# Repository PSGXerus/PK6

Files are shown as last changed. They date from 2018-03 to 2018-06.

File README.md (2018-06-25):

# Raspberry Pi 3 powered kiosk

- [Introduction](#introduction)
  - [Scope](#scope)
  - [Audience](#audience)
  - [Documentation](#documentation)
  - [Acronyms](#acronyms)
- [1. Components](#1-components)
- [2. Milestones (Roadmap)](#2-milestones-roadmap)
- [3. Software](#3-software)
- [4. Hardware](#4-hardware)
- [5. Power consumption](#5-power-consumption)
- [6. Installation](#6-installation)
- [Appendix](#appendix)
  - [Useful webpages](#useful-webpages)

## Introduction

### Scope

This repository shows the work in progress of the TI project summer 2018 no. 6. 

### Audience

This document should be a guide for future participants in the project. 

### Documentation

* [Automatic TOC generation](http://tableofcontent.eu/)
* [General form](https://docs.gitlab.com/ee/user/markdown.html)
* [Table generator](http://www.tablesgenerator.com/markdown_tables)
* Markdown editor 
	- Windows & Linux: [Ghostwriter](https://wereturtle.github.io/ghostwriter/)
	- MacOS: [Macdown](https://macdown.uranusjr.com/)

### Acronyms

**OS** Operating System

## 1. Components

| Unit | Component |
|:---|:---:|
| Compute unit | Raspberry Pi 3 B |
| Screen | [Waveshare 10.1" HDMI LCD(H)](https://www.waveshare.com/wiki/10.1inch_HDMI_LCD_(H))|
| OS | [Raspbian Stretch](https://www.raspberrypi.org/downloads/raspbian/) |

## 2. Milestones (Roadmap)

- [x] Building development system
- [x] Putting touchscreen into operation
- [x] Creating standby logic
    - [x] Concept
    - [x] Design
    - [x] Test
- [x] Hosting a fullscreen application
	- [x] Implement button functionality
		- [x] Build button test setup
		- [x] Create python software drivers
		- [x] Solder buttons
	- [x] Set up GUI
		- [x] Implement GUI
		- [x] Test GUI on the Raspberry 
	- [x] Integration
- [x] Creating a case
	- [x] Concept
	- [x] Design
	- [x] Manufacture
	- [x] Paint
- [x] Integrating admin access
- [x] Writing setup-bashscript

## 3. Software

- Modifications on the OS can be found in [this](documentation/mods.md) document.
- The application development is descibend in [this](documentation/sw.md) document.
- The documentation for the modified bootloader can be found [here](documentation/bootloader.md).

## 4. Hardware

- Everything concerning hardware is described in [this](documentation/hw.md) document.

## 5. Power consumption

|Nominal Voltage|Measured Current|Consumed Power|
|---|---|---|
|12V |~0.5A |~6W |

## 6. Installation

1. Download [Raspbian](https://www.raspberrypi.org/downloads/raspbian/)
2. Put a freshly formatted micro SD card into your laptop
3. Start a terminal
4. Navigate with ```cd [path]``` and ```ls``` to the folder with the downloaded Image
5. Type the following command

    ```shell
    $ sudo fdisk -l
    ```

6. Memorize the name for the SD card handle (probably /dev/mmcblk0)
7. Type this name as the \<PATH\> in this command

    **BE CAREFUL**: If \<PATH\> is not correct ```dd``` could wipe your laptops storage!!!
    
    ```shell
    $ sudo umount <PATH>
    $ sudo dd bs=1M if=./<NAME_OF_THE_IMAGE> of=<PATH>
    ```
7. Mount the SD cards boot partition
8. Add the following to the end of *cmdline.txt* on the boot partition, with \<IP\>, \<GATEWAY\> and \<BROADCAST\> set as desired

    ```
    ip=<IP>::<GATEWAY>:<BROADCAST>:rpi:eth0:off
    ```
9. Add the following to the end of *config.txt* on the boot partition

    ```
    dtoverlay=gpio-poweroff,active_low="y"
    dtoverlay=gpio-shutdown,gpio_pin=20
    ```
10. Unmount the SD card and put it into the Raspberry Pi you want to use in the kiosk
11. Boot and open a terminal
12. Use the following commands

    ```shell
    $ passwd
    # Set a password
    # Check if network is available
    $ ping 8.8.8.8
    $ git clone https://github.com/PSGXerus/PK6_2018.git
    $ cd PK6_2018/install
    $ sudo ./initialize_pi.sh &> ~/install.log
    ```

## Appendix

### Useful webpages
  
[Add a power button to the Raspberry](https://howchoo.com/g/mwnlytk3zmm/how-to-add-a-power-button-to-your-raspberry-pi)
[Original project descripton (DE)](http://www.netzmafia.de/skripten/hardware/RasPi/Projekt-Kiosk/)  
[Pi 3 Kiosk (DE)](https://itrig.de/index.php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)  
[Various Information on the Raspberry Pi (DE)](http://www.elektronik-kompendium.de/sites/raspberry-pi/index.htm)

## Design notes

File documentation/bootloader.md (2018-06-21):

# Modified Plymouth boot splashscreen

Boot splash screens on Raspbian are currently displayed by plymouth.  
Plymouth is an application that runs very early in the boot process
(even before the root filesystem is mounted!) that provides a graphical
boot animation while the boot process happens in the background.
Plymouth themes are usually written in C but Plymouth also ships a script parser
which can be used to create simple boot splash screens.

- [Developing Plymouth splash screens](#developing-plymouth-splash-screens)
- [Installing the splash screen from this repository](#installing-the-splash-screen-from-this-repository)
- [Further reading](#further-reading)

## Developing Plymouth splash screens

An animation for plymouth can be created with the help of the 3D tool [blender](https://www.blender.org/download/).

To develop your own plymouth script install the following packages.

```shell
$ sudo apt install plymouth-themes
$ sudo apt install plymouth-x11
```

A sample script can now be found in */usr/share/plymouth/themes/script*.

```shell
$ sudo plymouth-set-default-theme script
$ cp <src/bootloder/test_plymouth.sh> .
$ ./test_plymouth.sh
```

Refer to [further reading](#further-reading) for more information on the scripting syntax.

## Installing the splash screen from this repository

Execute the following commands.
 
```shell
$ sudo cp -r <src/bootloder/raspberry_pi> /usr/share/plymouth/themes
$ sudo plymouth-set-default-theme raspberry_pi
$ sudo cp -r <src/bootloder/plymouth-quit.service.d> /etc/systemd/system 
$ sudo systemctl daemon-reload
```

## Further reading

- [Plymouth scripting guide](http://brej.org/blog/?p=158)
- [Plymouth scripting Syntax](https://www.freedesktop.org/wiki/Software/Plymouth/Scripts/)
- [Plymouth git repository](https://github.com/sergeysova/plymouth)

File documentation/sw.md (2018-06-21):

# Kiosk System

###### Hochschule München - Projekt Technische Informatik Nr. 6 - SS18

## Einleitung

Der sogenannte Kiosk-Modus eines Betriebssystems zeichnet sich durch eingeschränkte Rechte für den Benutzer aus, um ausschließlich gewünschte Inhalte zu zeigen. 
Möchte man eine Python Applikation für einen Raspberry Pi mit Raspbian programmieren, die Webinhalte oder lokale HTML Dateien in einem Kiosk Modus anzeigt und per Hardware-Taster kontrollierbar macht, ist folgendes Vorgehen möglich.

### Wahl der graphischen Benutzeroberfläche

Python bietet einige GUI Pakete wie *TKinter*, *PySide* oder *PyQT*. Da sich die Umsetzung einer Web-Ansicht mit dem Python Standard *TKinter* allerdings nur schwierig umsetzen lässt, ist *PyQt5* besser geeignet. Zudem ist *Qt* ist ein plattformübergreifender Standard für die Entwicklung von graphischen Benutzeroberflächen und für den Raspberry Pi bestens geeignet. Die Evaluierung anderer Pakete wurde deshalb nicht mehr in Betracht gezogen.

### GPIO Ports verwenden

Der Raspberry Pi besitzt einige General Purpose Input Output (GPIO) Ports, deren Status mithilfe der Python GPIO Methoden ausgelesen werden kann. Die Hardware Komponenten sind daher an diese Ports angeschlossen.

### Taster

Im Kiosk Projekt kommen 3 Taster zum Einsatz. Hiervon ist ein Taster Teil des Drehgebers, der aber genauso angesprochen wird wie die restlichen beiden Taster. Die Taster sind jeweils mit externen 10 kOhm Pull-Up Widerständen verbunden (Invertierte Logik). Details befinden sich in der Code Dokumentation.

### Drehgeber

Bei der Drehung um einen Einrastpunkt emittiert ein typischer Drehgeber auf seinen 2 Ausgangspins einen 2 Bit Gray Code. Jeder Schritt, der meistens durch einen physikalischen Klick begleitet wird, generiert dabei eine Sequenz an 5 Output Codes.

Position  | Bit1 | Bit2
--------- | ---- | ------
Start 		| 0		| 0
1/4  		| 1		| 0
1/2			| 1		| 1
3/4			| 0		| 1
Ende		| 0 	| 0

Die Richtung der Drehbewegung wird durch den Ablauf der Codetabelle festgelegt. Entweder wird sie von oben nach unten, oder umgekehrt durchlaufen.

Über eine State Machine wird der richtige Durchlauf der Codefolgen nachverfolgt. Vorteil dieser Methode ist unter anderem Störfestigkeit (Bei einem eigentlich nicht möglichen Übergang der Pins von 10 auf 01 wird zum Beispiel die State Machine wieder auf 00 resettet). Außerdem ist der Drehgeber hierdurch entprellt, ohne zusätzliche Entprell-Kondensatoren oder Software Algorithmen zu benötigen.

Die 2 Bit Pins des Drehgebers sind jeweils mit 10 kOhm Pull-Up Widerständen auf Vcc (3.3V am Raspberry) verbunden.

### Threading und Signals

Sobald eine Python Applikation mit ``app-exec_`` gestartet wurde, werden keine weiteren Methodenaufrufe mehr zugelassen. Damit die GUI Applikation und die GPIO Funktion also gleichzeitig ablaufen und kommunizieren muss mit ``Threading`` gearbeitet werden. Die Übertragung zwischen den Threads erfolgt über sogenannte ``Signals``. 

## Code Dokumentation

### Pakete importieren

**GUI Pakete**

```
from PyQt5.QtCore import QUrl, Qt
from PyQt5.QtWidgets import QApplication, QWidget
from PyQt5.QtWebKitWidgets import QWebView
from PyQt5.QtWebKit import QWebSettings
```

Die Unterpakete von PyQt5 werden später erläutert.

**Interaktion mit dem File-System**

```
import os

```

``os`` dient unter anderem zur Pfadmanipulation mittels ``os.path`` oder zur Pfaditeration mittels ``os.walk``.

**Python Interpreter**

```
import sys
```

Mit ``sys.argv[1]`` lässt sich beispielsweise der erste Parameter beim Aufruf über die Kommandozeile angeben. Das ``sys`` Modul stellt also Informationen über den Python-Interpreter zur Verfügung.

**Zeit Funktionen**

Beispielsweise zum endlosen Warten.

```
import time
```

**GPIO**

```
import RPi.GPIO as GPIO

```

**Threading und Signals**

```
from PyQt5.QtCore import QThread, pyqtSignal

```

Die Applikation muss im *Main Thread* laufen (d.h. nicht in einem eigenem Thread) und von dort aus können parallel beliebig viele weitere Threads gestartet werden, sofern sie als ``QThread`` initialisiert worden sind. Über ``signals`` können die Threads dann miteinander und mit dem *Main Thread* kommunizieren. 

### Globale Variablen definieren

```
fileList = list()
fileCounter = 0

```

``fileList`` wird als leere Liste initialisiert um später die Namen der anzuzeigenden HTML-Dateien zu speichern. 

Der ``fileCounter`` wird mit 0 initialisiert und später erhöht oder erniedrigt, je nachdem ob die vorherige oder die nächste Seite ausgewählt wird. Der Zahlenbereich wird durch die Länge von ``fileList``bestimmt.

### Methoden

**Das Verzeichnis mit den (HTML) Dateien auslesen**

```
def setDir():
    if len(sys.argv) is 1:
    	print("Please specify HTML directory as first argument")
    	sys.exit()
    directory = os.path.join(os.path.abspath(sys.argv[1]), '')
    return directory

```

Das Verzeichnis kann als erstes Argument in der Kommandozeile angegeben werden. In der Variablen ``directory`` wird der Pfad zu den HTML Dateien gespeichert. ``join`` erzeugt aus allen übergebenen Parametern einen ``/``separierten Pfad. In diesem Fall werden der Pfad und ein Leerstring zusammengefügt, was nichts anderes bedeutet, als ein ``/``anzuhängen. 

**Eine Datei öffnen** 

```
def openFile(file):
    dir = setDir()
    path = os.path.join(dir, file)
    try:
       with open(path) as f:
            data = f.read()
       return data
    except OSError as e:
        if e.errno == errno.ENOENT:
            print(e)
        else:
            raise          
```

Dabei wird die erstellte ``setDir`` Methode zum Auslesen des Verzeichnisses verwendet, der übergebene Dateiname ``file``geöffnet und die Datei mit ``read`` ausgelesen. Im Fehlerfall wird eine Exception geschmissen (vergleichbar zur anderen Programmiersprachen). Wenn der Fehler ein ``File not found`` Fehler ist, wird dieser ausgegeben. Ansonsten wird der Zähler für die Fehlerart erhöht. Jeder Fehler ist einer Nummer zugeordnet (z.B. ``ENOENT = 2``).

**Die Liste mit den Dateien füllen** 

```
def initFileList():
    directory = setDir()
    fileSet = set() 
    for root, dirs, files in os.walk(directory): 
        for fileName in files:
            if fileName.endswith('.html'):
                fileSet.add(os.path.join(root[len(directory):], fileName))
    fileList = list(fileSet) 
    fileList.sort()
    return fileList
```

Hier wird wieder die ``setDir``Methode verwendet um den angegebenen Pfad zu erhalten. Danach wird eine Liste als ``set`` initialisiert, welches keine doppelten Elemente enthalten kann. Falls diese Eigenschaft nicht gewünscht ist, kann mit ``list.append()``gearbeitet werden. 

 Alle Dateinamen mit der spezifizierten Endung werden dem ``set`` hinzugefügt und anschließend wieder in eine Liste umgewandelt und zurückgegeben. Da ein ``set`` nicht sortiert ist, wird das mit ``sort``noch erledigt. 

### Klassen

Der Python Code enthält eine Klasse für die graphische Oberfläche und eine für die GPIO Funktion. 

#### GUI 

Die Klasse wird als ``QWebView`` initialisiert. Diese ist mit Methoden ausgestattet, welche unter anderem Webinhalte und lokale HTML Dateien anzeigen können.

```
class Infoscreen(QWebView):      
```

Es folgen nun sieben interne Funktionen:

Zuerst die sich rekursiv aufrufende Initialisierungsfunktion.

```
def __init__(self):
    super(Infoscreen, self).__init__()
    self.setWindowTitle('Infoscreen')
    self.titleChanged.connect(self.adjustTitle)
``` 
 
Nach dem Aufruf von ``__init__`` können Einstellungen für das Fenster vorgenommen werden. In diesem Fall wird nur der Titel bearbeitet. 

``` 
def adjustTitle(self):
    self.setWindowTitle(self.title())

def disableJS(self):
    settings = QWebSettings.globalSettings()
    settings.setAttribute(QWebSettings.JavascriptEnabled, False)
```

``adjustTitle`` setzt den Titel der Anwendung und ``disableJS`` bietet die Möglichkeit JavaScript Funktionen ein -oder auszuschalten. Mit den Methoden der ``QWebSettings`` können die Einstellungen gespeichert werden, welche dann von der ``QWebView`` genutzt werden. 

```
def keyPressEvent(self, event):
    if event.key() == Qt.Key_Escape:
        self.close()
```

In ``keyPressEvent`` kann eine Taste oder Tastenkombination angegeben werden, um die Anwendung zu schließen und aus dem Vollbildmodus zurückzukehren. Das ist in der Entwicklungsphase und später für den Administrator sehr hilfreich.

```
def switchPage(self, fileIndex):
    fileList = initFileList()
    try:
        file = fileList[fileIndex]
        html = openFile(file)
        self.setHtml(html,QUrl.fromLocalFile(setDir()))
    except IndexError as e:
        print(e)
```

Die Methode ``switchPage`` nutzt alle erstellten globalen Methoden zur Anzeige der nächsten oder vorherigen HTML Seite. Der Parameter ``fileIndex`` bestimmt, welche der in ``fileList`` enthaltenen Dateien ausgewählt werden soll. Danach wird diese Datei geöffnet und mithilfe der ``QWebView``- Funktion ``setHTML`` in die Oberfläche geladen. Entscheidend ist dabei die Verwendung von ``QUrl`` zur Unterscheidung von lokalen und gehosteten Quelldateien. Falls der übergebene Index größer als die Länge der Dateiliste ist, wird ein ``IndexError`` geschmissen. Da dieser allerdings von der Liste abhängt, kann das im Normalfall nicht passieren.

```
def update(self, action):
    global fileCounter
    fileIndex = len(initFileList())
    if action == "fwd":
        if fileCounter<fileIndex-1:
            fileCounter = fileCounter + 1
        else:
            fileCounter = 0
        self.switchPage(fileCounter)
    elif action == "bwd":
        if fileCounter>0:
            fileCounter = fileCounter -1
        else:
            fileCounter = fileIndex-1
        self.switchPage(fileCounter)
    elif action == "home":
        fileCounter = 0
        self.switchPage(fileCounter)
    elif action == "up":
        self.page().mainFrame().scroll(0,-100)
    elif action == "down":
        self.page().mainFrame().scroll(0,100)
    else:
        pass
```

Hier wird der globale ``fileCounter`` je nach Signal erhöht oder erniedrigt und die nächste oder vorherige Seite mit ``switchPage`` angezeigt. Außerdem sind zwei Events für die Scroll-Funktion und eines für die Rückkehr zu ersten Seite ``home`` angelegt. Der Zähler hängt von der Länge der Dateiliste ab und ist durch diese begrenzt. Wenn die letzte Datei erreicht wurde, wird wieder die erste angezeigt (und anders herum).

```
def connect_input(self, inputthread):
    inputthread.update_signal.connect(self.update)
```

Die letzte interne Methode dient zur Verbindung der Threads mit der GUI Klasse. Die Methode wird beim Start der Anwendung jeweils einmal für alle vorhandenen Threads (in diesem Fall nur der GPIO Thread) aufgerufen. Der Übergabeparameter ist die Thread Klasse, sofern sie als ``QThread`` initialisiert worden ist.

### GPIO

Die zweite Klasse reagiert auf Änderungen an den GPIO Pins. Sie wird, wie angesprochen, als ``QThread`` angelegt:

```
class GPIO_Thread(QThread):
```

Als nächstes wird eine Signalvariable erstellt, die das ``pygtSignals`` Paket nutzt, um eine Verbindung mit der ``update`` Methode der GUI-Klasse herzustellen.

```
update_signal = pyqtSignal(str, name='update')
```

Bei der Initialisierung wird die Methode wieder rekursiv aufgerufen und der Thread-Zustand mit 0 vorbelegt:

```
def __init__(self):
        super(GPIO_Thread, self).__init__()
        self.state = 0
```

Danach wird die ``QThread`` Methode ``run`` überschrieben und der gesamte *GPIO* Code dort platziert.

```
def run(self):
```

<u>Schritt 1</u>: Integer-Variablen für die Taster und den Drehgeber definieren:

```
tasterPin1 = 11
tasterPin2 = 13
tasterPin3 = 15  
drehgeberPin1 = 16
drehgeberPin2 = 18
```

Die Zahlen entsprechen den Nummern der Raspberry Pins, welche als GPIO Pins konfiguriert sind. Die Belegung ist nochmals in den folgenden Tabellen zusammengefasst:

**Taster Pinbelegung**

Taster |	Pin    |	GPIO
------ | ------- | -------
Taster1 | 11	    | 17
Taster2 | 13     | 27
Taster3 (Drehgeber) | 15 | 22

**Drehgeber Pinbelegung**

Drehgeber |	Pin    |	GPIO
------ | ------- | -------
Pin1 (Bit1) | 16 | 23
Pin3 (Bit2) | 18 | 24

**VCC/GND**

-|	Pin    
------ | ------- 
VCC (3.3V) | 17
GND | 9  

$\:$
<u>Schritt 2</u>: GPIO Board Modus setzen. 

```
GPIO.setmode(GPIO.BOARD)
```

Das bedeutet, dass die Pin Nummern auf der Raspberry Pi Platine verwenden werden. Eine Alternative sind die GPIO-Pins mittels ``GPIO.BCM``, welche sich allerdings in den Versionen des Raspberry Pi unterscheiden können und somit keine Eindeutigkeit gegeben ist.

<u>Schritt 3</u>: Eingänge definieren.

```
GPIO.setup(tasterPin1, GPIO.IN)
GPIO.setup(tasterPin2, GPIO.IN)
GPIO.setup(tasterPin3, GPIO.IN)
GPIO.setup(drehgeberPin1, GPIO.IN)
GPIO.setup(drehgeberPin2, GPIO.IN)
```

<u>Schritt 4</u>: Konstanten für den Drehgeber festlegen.

```
 DIR_NONE = 0x0
 DIR_CW = 0x10
 DIR_CCW = 0x20
 
 R_START = 0x0
 R_CW_FINAL = 0x1
 R_CW_BEGIN = 0x2
 R_CW_NEXT = 0x3
 R_CCW_BEGIN = 0x4
 R_CCW_FINAL = 0x5
 R_CCW_NEXT = 0x6
```

Die ersten drei Konstanten repräsentieren eine Links-, eine Rechts- oder keine Drehung. Die restlichen Konstanten sind die Zustände der Zustandsmaschine, welche im einführenden Kapitel erläutert wurde. 

<u>Schritt 5</u>: Die Zustandstabelle anlegen:

```
ttable = [[R_START, R_CW_BEGIN, R_CCW_BEGIN, R_START],
         [R_CW_NEXT, R_START, R_CW_FINAL, R_START|DIR_CW],
         [R_CW_NEXT, R_CW_BEGIN, R_START, R_START],
         [R_CW_NEXT, R_CW_BEGIN, R_CW_FINAL, R_START],
         [R_CCW_NEXT, R_START, R_CCW_BEGIN, R_START],
         [R_CCW_NEXT, R_CCW_FINAL, R_START, R_START|DIR_CCW],
         [R_CCW_NEXT, R_CCW_FINAL, R_CCW_BEGIN, R_START]]

```

<u>Schritt 6</u>: Den Status vorinitialisieren:

```
self.state = R_START
```

<u>Schritt 7</u>: Den drei Tastern und dem Drehgeber eine Event Methode zuordnen (Taster 2 und 3 analog):

```
def call1(channel):
    self.update_signal.emit("fwd")           
```

Der Übergabeparameter ist der zugehörige Kanal und mithilfe der ``emit`` Methode wird ein Signal gesendet. 

Zum Vergleich: In der GUI-Klasse wurde ebenfalls eine Methode mit ``update_signal`` erstellt - dort aber eine ``connect`` Funktion aufgerufen um die graphische Oberfläche als Empfänger festzulegen. 

Beim Drehgeber muss vor dem senden noch ermittelt werden, welche Aktion genau ausgeführt wurde. Dazu wird in ``pinstate`` zunächst die aktuelle Pin Nummer gespeichert, der passende Wert in der Matrix gesucht und auf ``DR_CW`` oder ``DIR_CCW`` geprüft. 

```
def call4(channel):
    pinstate = ((GPIO.input(drehgeberPin2) << 1)| GPIO.input(drehgeberPin1))
    self.state = ttable[self.state & 0xf][pinstate]
    if self.state ==  DIR_CW:
        self.update_signal.emit("down")
    elif self.state == DIR_CCW:
        self.update_signal.emit("up")
```

Wird ein Taster gedrückt, löst dieser bei einer fallenden Flanke einen Interrupt aus, und springt in eine der oben erwähnten Callback Funktionen, in der weitere Funktionalität ausgeführt wird. Jeder Taster hat hierbei eine eigene Callback Funktion.

Mittels der GPIO.RPI Library wird ebenfalls ein softwareseitiges Entprellen (bouncetime = 200ms) eingeschaltet (Die anderen Taster analog).

```  
GPIO.add_event_detect(tasterPin1, GPIO.FALLING, callback = call1function, bouncetime = 200)
```

Für den Drehgeber sieht das ähnlich aus - nur ohne Bouncetime (Drehgeber Pin 2 analog):

```
GPIO.add_event_detect(drehgeberPin1, GPIO.BOTH, callback = call4)
```

Informationen können mit den Callback Funktionen nur durch globale Variablen weitergereicht werden.

<u>Schritt 8</u>: Mit einer Endlosschleife dafür sorgen, dass die ``run`` Methode während der Laufzeit nicht verlassen wird:

```
while True:
     time.sleep(1)
```

Nach der ``run`` Methode folgt noch eine "Aufräum" -Funktion:

```
   def __del__(self):
        GPIO.cleanup()
```

Zum Schluss muss die Applikation noch gestartet werden (Als ``QApplication`` initialisiert).

```
def main():
    app = QApplication(sys.argv)
    screen = Infoscreen()
    screen.switchPage(0)
    screen.showFullScreen()
    inputthread = GPIO_Thread()
    inputthread.start()
    screen.connect_input(inputthread)
    sys.exit(app.exec_())

if __name__ == '__main__':
    main()
```

Weiter wird die GUI Klasse ``Infoscreen`` aufgerufen und die erste HTML Seite mit ``switchPage`` geladen. Danach wird der Vollbildmodus aktiviert und der GPIO Thread gestartet. Wenn die GPIO Instanz existiert, kann die oben erwähnte ``connect_input`` Methode für den Thread aufgerufen werden. 

Als letztes geschieht der ``main``Aufruf und der Infoscreen startet.

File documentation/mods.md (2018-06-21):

# Mods on Raspbian for the Kiosk functionality

- [Pre-boot modifications](#pre-boot-modifications)
- [Software installations](#software-installations)
- [Modifications on the bootloader](#modifications-on-the-bootloader)
- [Activate SSH Server](#activate-ssh-server)
- [Allow root permission via SSH](#allow-root-permission)
- [Connect to Raspberry](#connect-to-rasperry)

## Pre-boot modifications

Added the following to the config.txt on the FAT partition of the SD card

```
max_usb_current=1
hdmi_group=2
hdmi_mode=1
hdmi_mode=87
hdmi_cvt 1024 600 6 0 0 0
```

## Software installations

Very useful tool for missing packages

```shell
sudo apt update
sudo apt install command-not-found
sudo update-command-not-found
```

Fix touchscreen pointing device

```shell
sudo apt install xserver-xorg-input-evdev
sudo mv /usr/share/X11/xorg.conf.d/40-libinput.conf /usr/share/X11/xorg.conf.d/40-libinput.conf_bak
reboot
```

Uninstall stuff that is not needed

```shell
sudo apt remove --purge libreoffice* wolfram-engine minecraft-pi sonic-pi python3-numpy smartsim timidity scratch nuscratch python3-pygame python-pygame python-tk python-picraft bluej claws-mail greenfoot nodered geany xpdf
sudo apt autoremove
sudo apt upgrade
```

Remove warning when starting any gtk+ application

```shell
sudo apt install at-spi2-core
```

Install packages for the Python PyQt graphical user interface

```
sudo apt-get update
sudo apt-get install qt5-default pyqt5-dev pyqt5-dev-tools
sudo apt-get install python3-pyqt5
sudo apt-get install python3-pyqt5.qtwebkit
reboot
```

## Modifications on the bootloader

In this section, devicetree overlays are used. For more information on the devicetree, check [this webpage](https://www.raspberrypi.org/documentation/configuration/device-tree.md).

First activate the GPIO-poweroff overlay which acts as feedback for the power board. Then activate the GPIO-shutdown overlay in order to be able to shutdown the PI with the click of a button.
Currently, the GPIO-poweroff overlay leaves the system with a kernel panic at the end of the power cycle because something tries to kill the init task. However this should not be a problem, as the storage is unmounted before.
Finally, the bootloader should not display any kind of messages.

```shell
sudo mount -t auto /dev/mmcblk0p1 /mnt/
sudo sh -c "echo dtoverlay=gpio-poweroff,active_low="y"\ndtoverlay=gpio-shutdown,gpio_pin=20 >> /mnt/config.txt"
sudo sh -c "sed -i 's/$/ logo.nologo consoleblank=0 vt.global_cursor_default=0/' /mnt/cmdline.txt"
sudo sh -c "sed -i 's/console=tty./console=tty3/g' /mnt/cmdline.txt"
sudo umount /mnt
sudo sh -c "sed -i 's/#kernel.printk = . . . ./kernel.printk = 0 0 0 0/g' /etc/sysctl.conf"
sudo sh -c "sed -i 's/ExecStart=-/sbin/agetty --autologin pi --noclear %I $TERM/ExecStart=-/sbin/agetty --skip-login --noclear --noissue --login-options "-f pi" %I $TERM/' /etc/systemd/system/autologin@.service"
sudo sh -c "sed -i 's/session    optional   pam_lastlog.so/#session    optional   pam_lastlog.so/' /etc/pam.d/login"
sudo sh -c "sed -i 's/session    optional   pam_motd.so/#session    optional   pam_motd.so/' /etc/pam.d/login"
sudo plymouth-set-default-theme spinfinity
```

## Activate SSH Server

For current Raspbian versions the ssh server is already installed. Just activate it:

```shell
sudo raspi-config
```

Select SSH and reboot.

For older versions the installation has to be done manually. Install, start and enable automatic start:

```shell
sudo apt-get install ssh
sudo /etc/init.d/ssh start
sudo update-rc.d ssh defaults
```

## Allow root permission via SSH

Login as user pi:

```shell
pi:raspberry
```

Set a new password for user "root". There is no password set by default.

```shell
sudo passwd
```

Call configurations for the SSH server

```shell
sudo nano /etc/ssh/sshd_config
```

Search for the following code block..

```shell
# Authentication:
LoginGraceTime 120
PermitRootLogin without-password
StrictModes yes
```
..and change like this:

```shell
# Authentication:
LoginGraceTime 120
PermitRootLogin yes
StrictModes yes
```

To save changes press STRG-X and enter two times.
Reboot afterwards

```shell
sudo reboot
```

## Connect to Raspberry

Get the IP of the pi:

```shell
hostname -I
```

Connect via terminal (Linux/MacOS) ..
(-Y allows the usage of graphical applications)

```shell
ssh -Y pi@IP
```
.. or Putty (Windows).

When a host key WARNING appears, the latest key has to be removed (it was generated in another session from the last person that accessed a pi from this computer).

So follow the instructions and delete the host key:

```shell
ssh-keygen -f "../.ssh/kown_hosts" -R IP
``` 

Where IP is the adress of the computer that should access the pi and .. is the path to the configuration file.

Close the connection afterwards:

```shell
exit
```

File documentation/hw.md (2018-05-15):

# Hardware

## Table of content

- [1. Power board spice simulation](#1-power-board-spice-simulation)
- [2. Power board schematic](#2-power-board-schematic)
- [3. CAD case design](#3-cad-case-design)
  - [3.1 Preparation](#31-preparation)
  - [3.2 Dimensions for the parts in the design](#32-dimensions-for-the-parts-in-the-design)
  - [3.3 Case prototypes](#33-case-prototypes)

## 1. Power board spice simulation

&#8594; directory: simulation

The power board should grand power to the Pi as long as it boots and until a feedback signal has been asserted. The power should be cut a short time after the feedback signal has been deasserted. 

The base design is heavily inspired by an [existing version of the power circuity](http://www.netzmafia.de/skripten/hardware/RasPi/Projekt-OnOff/index.html).

The final design has been simulated in [LTSpice](http://www.analog.com/en/design-center/design-tools-and-calculators/ltspice-simulator.html).

## 2. Power board schematic

&#8594; directory: schematic

Additional features for this specific power board are:

1. A 12V to 5V DC/DC conversion to power the whole system from 1 power supply
2. Polarity protection for the barrel plug in case a wrong power supply is used
3. A way to provide efficient power cutting without leakage current

The features were implemented in the following way

1. A switching converter for maximum efficiency
2. [Protection via a MOSFET](http://www.ti.com/lit/an/slva139/slva139.pdf) because a series diode would cause a voltage drop and a parallel diode would need a fuse
3. A 5V relay with an RC element, that keeps the switching current and reduces the hold current

## 3. CAD case design

&#8594; directory: CAD

### 3.1 Preparation

Software: [FreeCAD](https://www.freecadweb.org/wiki/Download)

In order to design a case, one should get hold of one of the various
Raspberry Pi 3 CAD designs from the web. For example from:

* [GrabCAD (personal, noncommercial use only)](https://grabcad.com/)
* [Thingiverse (creative common licenses)](https://www.thingiverse.com/)

All the other designs can be found in the folder CAD.
A Raspberry Pi 3 design can also be created by oneself using the schematics
from [the Rasperry Pi documentation](https://www.raspberrypi.org/documentation/hardware/raspberrypi/mechanical/README.md).

### 3.2 Dimensions for the parts in the design

* [LCD screen](https://www.waveshare.com/img/devkit/LCD/10.1inch-HDMI-LCD-with-Holder/10.1inch-HDMI-LCD-with-Holder-size.jpg)
* [LCD controller board](http://www.waveshare.com/w/upload/5/51/10.1inch-hdmi-lcd-control-board-dimension.jpg)
* [Lock switch front](https://docs-emea.rs-online.com/webdocs/0eff/0900766b80eff837.pdf) and [back](http://www.produktinfo.conrad.com/datenblaetter/750000-774999/753963-da-01-de-Schluesselschalter_Gesamtlaenge_47mm.pdf)
* Power board &#8594; see the *.brd*-file in the *schematic* directory

### 3.3 Case prototypes

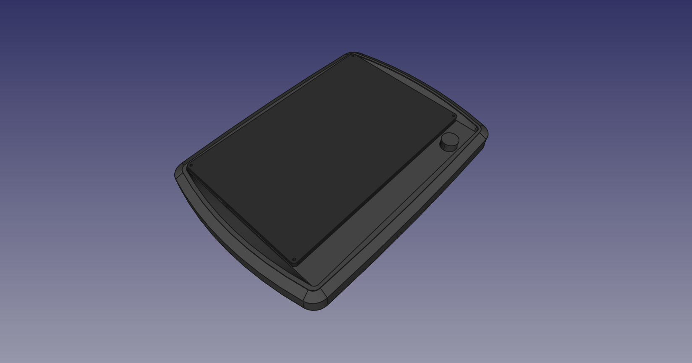
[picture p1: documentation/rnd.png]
  
**[Premade case for an exposed touchscreen kiosk from RND](https://www.distrelec.de/Web/Downloads/_t/ds/RND_455-00355_30064576_mcd_eng_tds.pdf)**

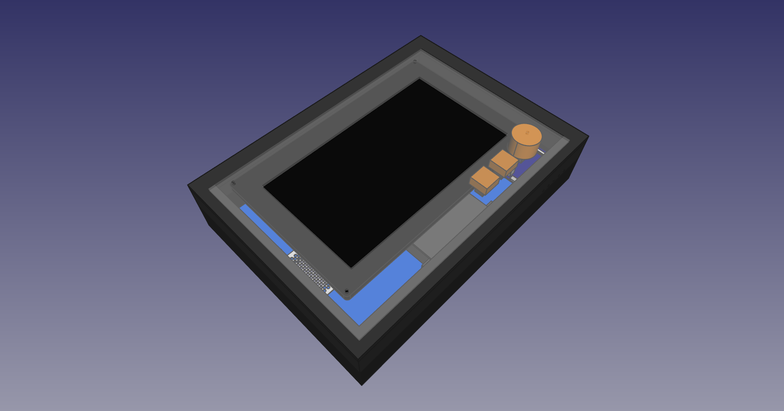
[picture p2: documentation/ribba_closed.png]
  
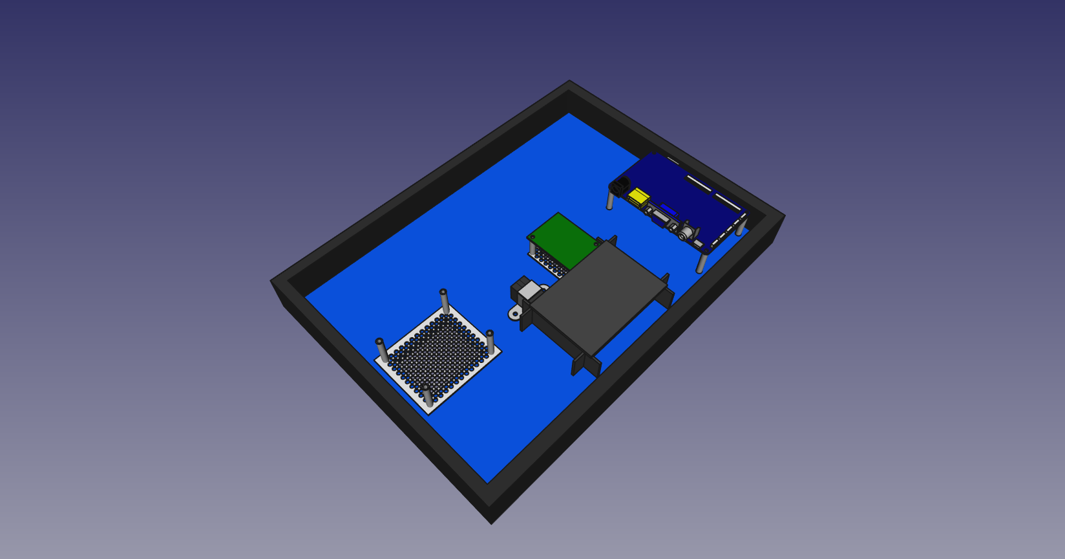
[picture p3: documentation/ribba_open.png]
  
**2 IKEA Ribba 21x30 mounted back to back for a protected button kiosk**

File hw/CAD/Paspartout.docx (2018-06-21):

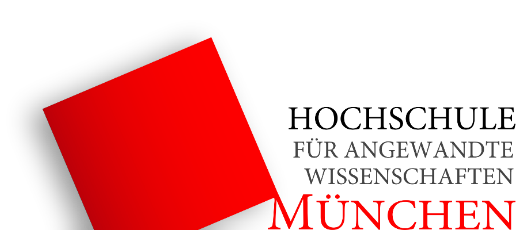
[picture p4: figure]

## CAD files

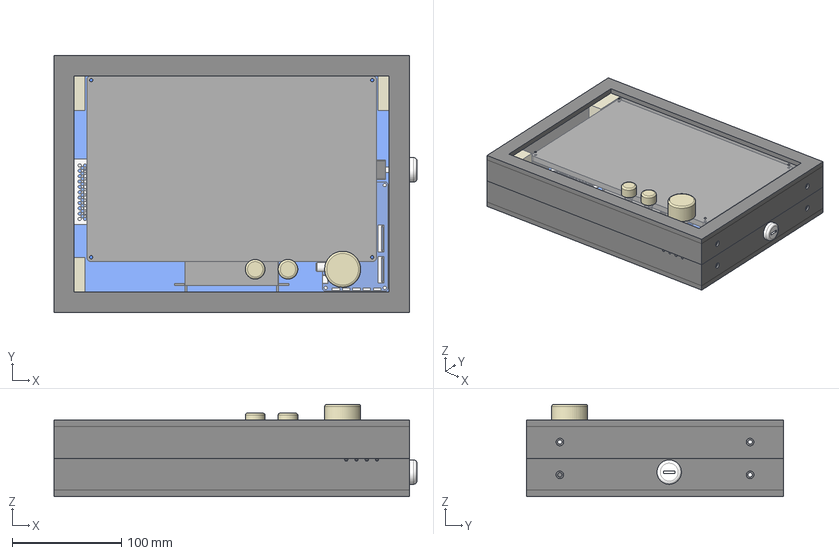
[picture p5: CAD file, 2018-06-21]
hw/CAD/case.FCStd
332.0 x 235.0 x 84.5 mm
GRILL001
GRILL
CASE_io_side004
CASE_io_top
CASE_io_side005
CASE_io_side
CASE_io_portside
CASE_2_backplate001
SCREEN
CASE_2_frame_front001
CASE_2_frame_back002
CASE_2_con003
CASE_2_con007
CASE_2_con005
LOCK_front
LOCK_pins
LOCK_pins001
LOCK_rails
LOCK_nut
LOCK_body
VGA_back001
PWR003
MUSB003
COM001
PCB002
RCC_base002
HDMI001
BTN_housing
LCD_controller_mounts
RCC_locks
BTN_knob
VGA_front
PWR004
MUSB004
POWER
POWER_mounts002
LCD_screen001
RCC_base004
PCB003
RCC_locks001
RJ45_adapter
RJ45_mount
ROTARY_nut
JOGWHEEL002
BUTTON_screw
BUTTON_body
BUTTON_piston
BUTTON_pins
BUTTON_nut
BUTTON_cap
KNOB004
BUTTON_screw001
BUTTON_body001
BUTTON_piston001
BUTTON_pins001
BUTTON_nut001
BUTTON_cap001
KNOB003
PI_mounts

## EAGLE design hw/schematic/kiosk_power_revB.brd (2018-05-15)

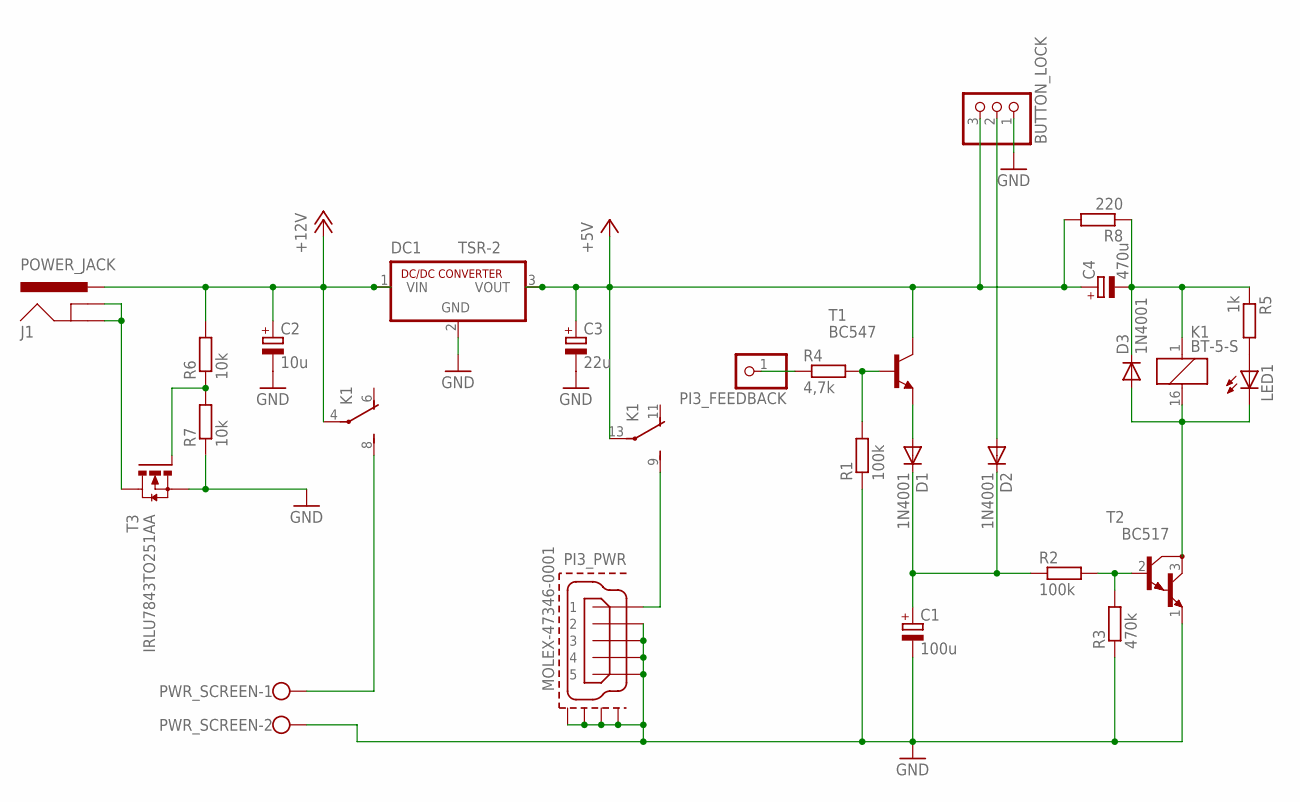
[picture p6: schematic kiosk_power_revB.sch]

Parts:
BUTTON_LOCK: PINHD-1X3/90; 1X03/90
C1: 100u; E2,5-5
C2: 10u; E2,5-6
C3: 22u; E2,5-5
C4: 470u; E2-5
D1, D2, D3: 1N4001; DO41-10
DC1: TSR-2; SIP3
J1: POWER_JACK; POWER_JACK_PTH
K1: BT-5-S; BT-XX-S
LED1: LED3MM
PI3_FEEDBACK: PINHD-1X1/90; 1X01/90
PI3_PWR: MOLEX-47346-0001; MOLEX-47364-0001
PWR_SCREEN: W237-102
R1, R2: 100k; 0207/7
R3: 470k; 0207/7
R4: 4,7k; 0207/7
R5: 1k; 0207/7
R6, R7: 10k; 0207/7
R8: 220; 0207/7
T1: BC547; TO92
T2: BC517; TO92
T3: IRLU7843TO251AA; TO251AA-V

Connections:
+5V: BUTTON_LOCK.3, C3.+, C4.+, DC1.3 (VOUT), K1.13, R8.2, T1.3 (C)
+12V: C2.+, DC1.1 (VIN), J1.PWR, K1.4, R6.2
GND: BUTTON_LOCK.1, C1.-, C2.-, C3.-, DC1.2 (GND), PI3_PWR.2, PI3_PWR.3, PI3_PWR.4, PI3_PWR.5, PI3_PWR.GND1, PI3_PWR.GND2, PI3_PWR.GND3, PI3_PWR.GND4, PWR_SCREEN.2, R1.1, R3.1, R7.1, T2.1 (E), T3.3 (S)
unnamed: J1.GND, J1.GNDBREAK, T3.2 (D)
unnamed: K1.8 (S), PWR_SCREEN.1
unnamed: C4.-, D3.C, K1.1, R5.1, R8.1
unnamed: PI3_FEEDBACK.1, R4.1
unnamed: K1.9 (S), PI3_PWR.1
unnamed: D3.A, K1.16 (2), LED1.K (C), T2.3 (C)
unnamed: BUTTON_LOCK.2, D2.A
unnamed: R6.1, R7.2, T3.1 (G)
unnamed: R1.2, R4.2, T1.2 (B)
unnamed: D1.A, T1.1 (E)
unnamed: C1.+, D1.C, D2.C, R2.1
unnamed: LED1.A, R5.2
unnamed: R2.2, R3.2, T2.2 (B)

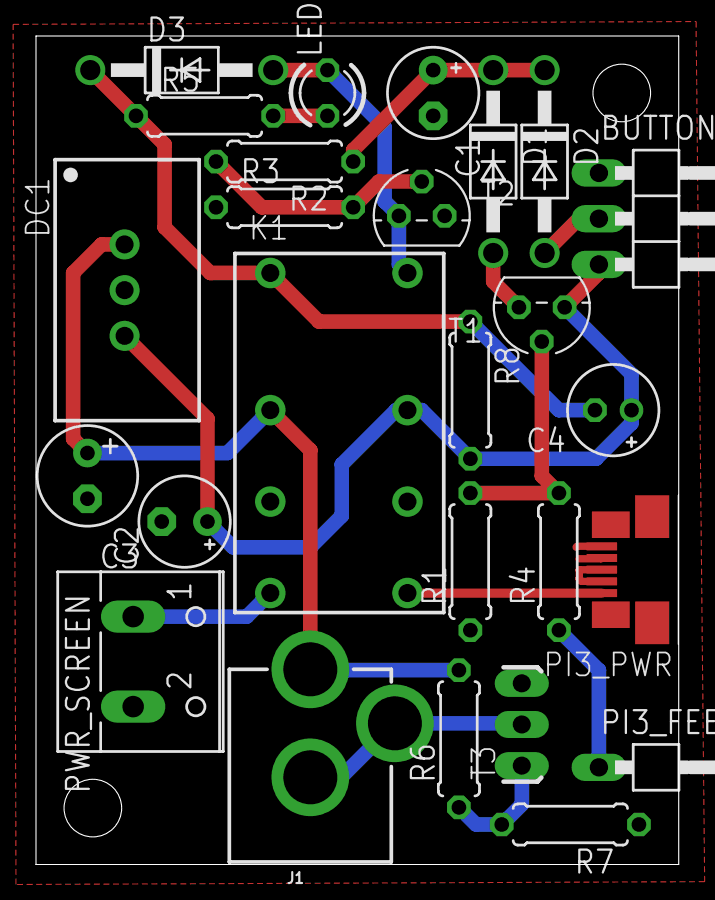
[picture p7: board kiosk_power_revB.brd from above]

Board: 2 copper layers, 35.7 x 46.0 mm, 26 parts (0 on the bottom side), 16 nets.

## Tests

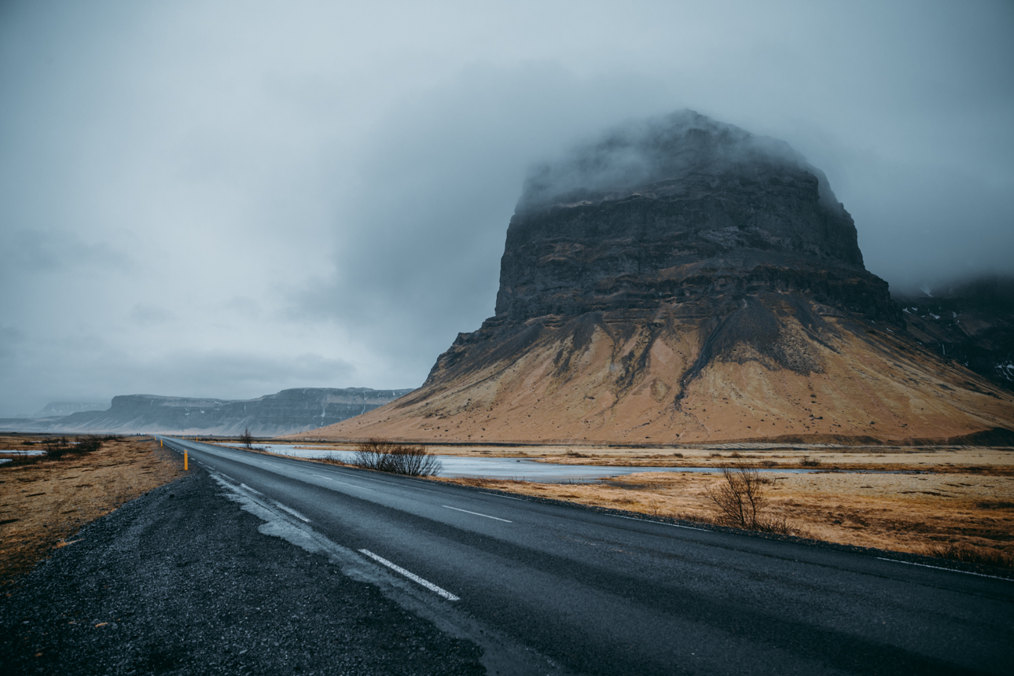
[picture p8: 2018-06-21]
src/python/GUI_Test/test2.png

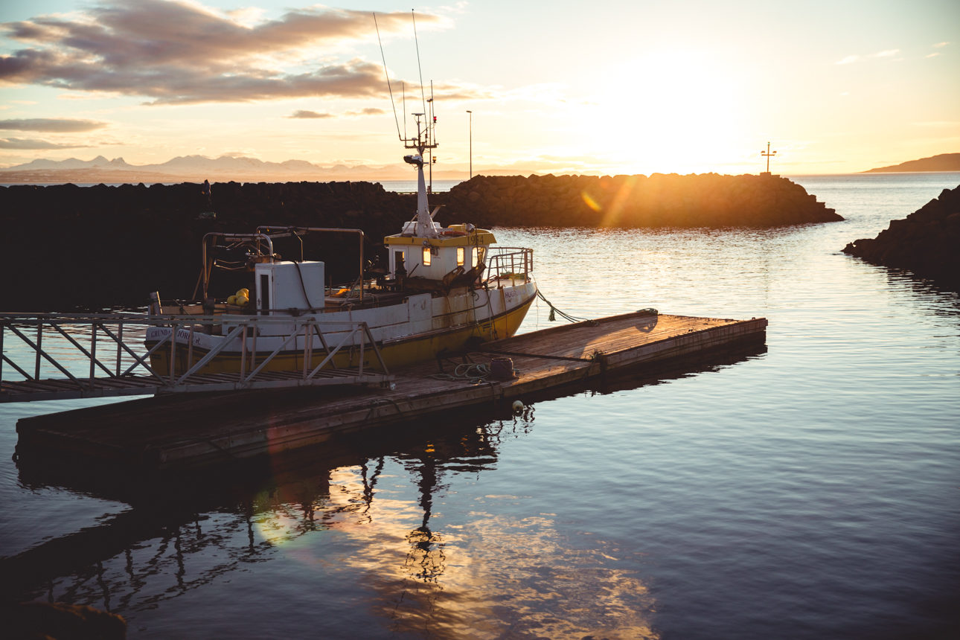
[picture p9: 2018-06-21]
src/python/GUI_Test/test6.png

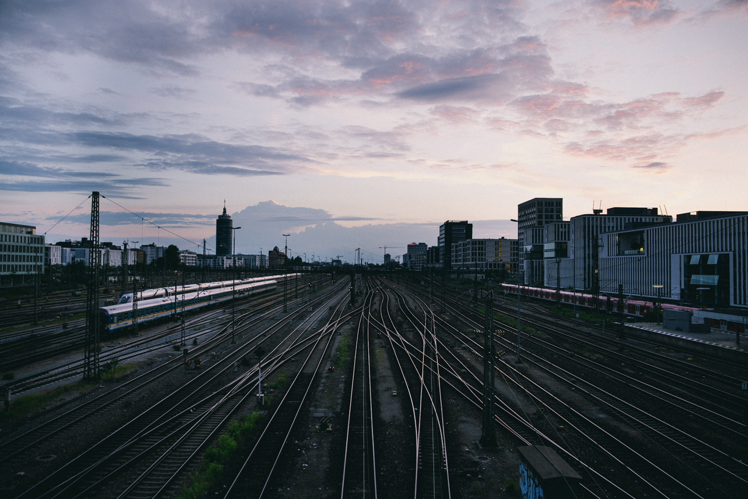
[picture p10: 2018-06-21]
src/python/GUI_Test/test4.png

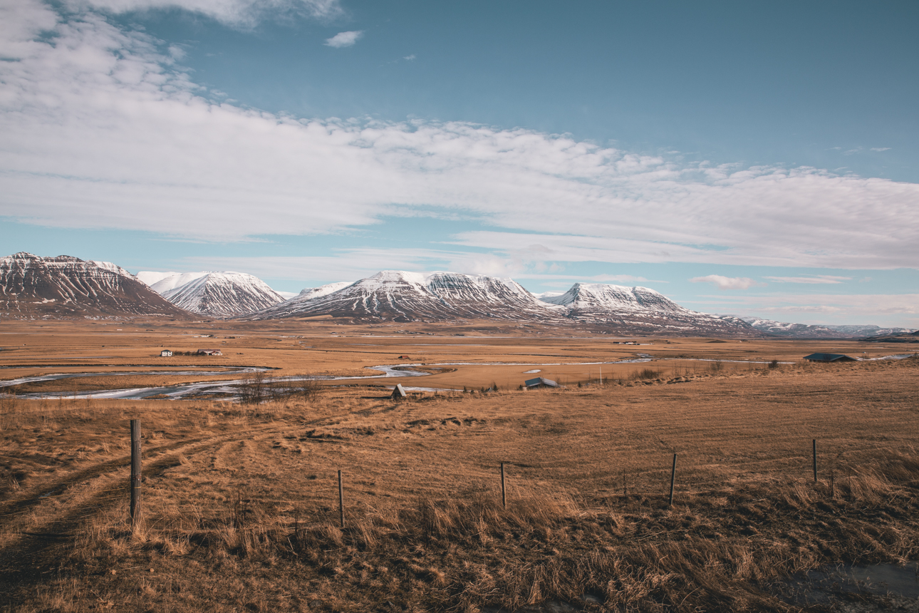
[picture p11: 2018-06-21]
src/python/GUI_Test/test1.png

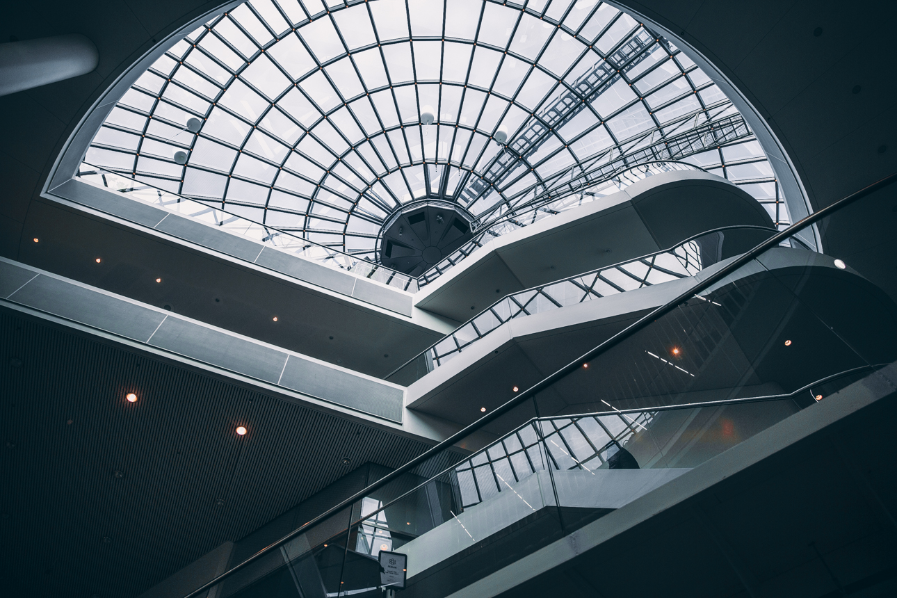
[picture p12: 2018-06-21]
src/python/GUI_Test/test5.png

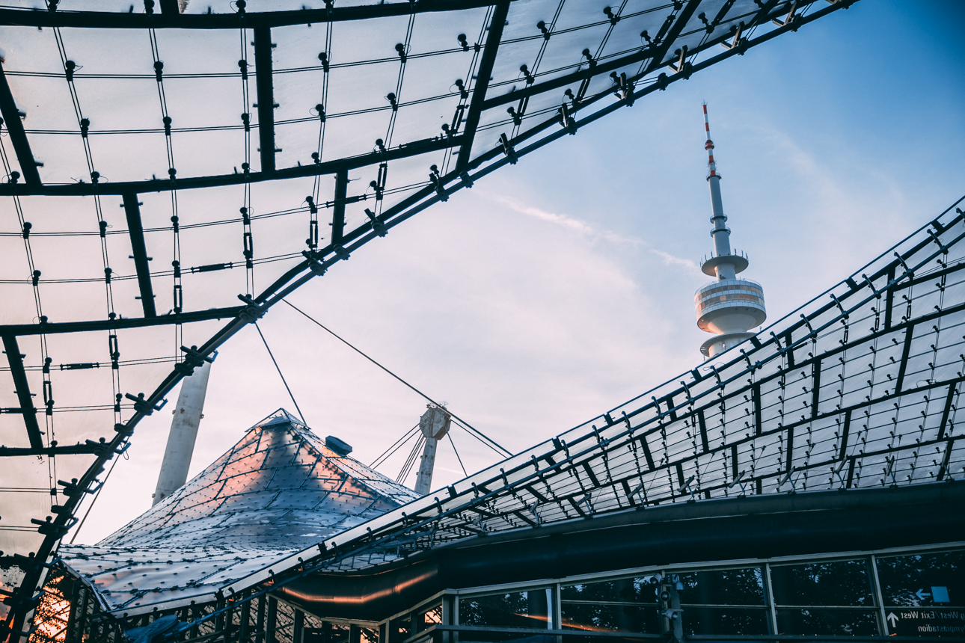
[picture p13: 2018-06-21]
src/python/GUI_Test/test3.png

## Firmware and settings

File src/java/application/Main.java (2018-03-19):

package application;

import javafx.application.Application;
import javafx.stage.Stage;
import javafx.scene.Scene;
import javafx.scene.layout.VBox;
import javafx.fxml.FXMLLoader;

/**
 * Main class of the info screen GUI 
 * @author FME
 *
 */
public class Main extends Application
{
	/**
	 * @param primaryStage - the main stage of the application
	 */
	@Override
	public void start(Stage primaryStage)
	{
		try 
		{
			VBox root = (VBox)FXMLLoader.load(getClass().getResource("Sample.fxml"));
			Scene scene = new Scene(root,600,400);
			scene.getStylesheets().add(getClass().getResource("application.css").toExternalForm());
			primaryStage.setScene(scene);
			primaryStage.setTitle("Infoscreen");
//			primaryStage.setFullScreen(true);
			primaryStage.show();
		} 
		catch(Exception e) 
		{
			/* Print to terminal */
			System.err.println(e.getMessage());
		}
	}

	/**
	 * Launch application
	 * @param args
	 */
	public static void main(String[] args) 
	{
		launch(args);
	}
}

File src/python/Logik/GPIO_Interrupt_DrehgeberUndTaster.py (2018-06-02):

import RPi.GPIO as GPIO
import time

#Pin Belegung
tasterPin1 = 11
tasterPin2 = 13
tasterPin3 = 15  #Taster vom Drehgeber
drehgeberPin1 = 16
drehgeberPin2 = 18

#Board Modus (Alternativ GPIO.BCM)
GPIO.setmode(GPIO.BOARD)

#Pin Setup als Eingaenge
GPIO.setup(tasterPin1, GPIO.IN)
GPIO.setup(tasterPin2, GPIO.IN)
GPIO.setup(tasterPin3, GPIO.IN)
GPIO.setup(drehgeberPin1, GPIO.IN)
GPIO.setup(drehgeberPin2, GPIO.IN)

value = GPIO.input(tasterPin1)
oldValue = 0
counter = 0

#Konstanten
DIR_NONE = 0x0
DIR_CW = 0x10
DIR_CCW = 0x20

R_START = 0x0
R_CW_FINAL = 0x1
R_CW_BEGIN = 0x2
R_CW_NEXT = 0x3
R_CCW_BEGIN = 0x4
R_CCW_FINAL = 0x5
R_CCW_NEXT = 0x6

#Full Table Deklaration
ttable = [[R_START, R_CW_BEGIN, R_CCW_BEGIN, R_START],
         [R_CW_NEXT, R_START, R_CW_FINAL, R_START|DIR_CW],
         [R_CW_NEXT, R_CW_BEGIN, R_START, R_START],
         [R_CW_NEXT, R_CW_BEGIN, R_CW_FINAL, R_START],
         [R_CCW_NEXT, R_START, R_CCW_BEGIN, R_START],
         [R_CCW_NEXT, R_CCW_FINAL, R_START, R_START|DIR_CCW],
         [R_CCW_NEXT, R_CCW_FINAL, R_CCW_BEGIN, R_START]]

#State Vorinitialisieren
state = R_START

def call1(channel):
    global counter
    counter = counter +1
    print (counter)

def call2(channel):
    global counter
    counter = counter -1
    print (counter)

def call3(channel):
    global counter
    counter = 0
    print (counter)


def call4(channel):
    global state
    pinstate = ((GPIO.input(drehgeberPin2) << 1)| GPIO.input(drehgeberPin1))
    state = ttable[state & 0xf][pinstate]
    if state ==  DIR_CW:
        print ("Rechts")
    elif state == DIR_CCW:
        print ("Links")

GPIO.add_event_detect(tasterPin1, GPIO.FALLING, callback = call1, bouncetime = 200)
GPIO.add_event_detect(tasterPin2, GPIO.FALLING, callback = call2, bouncetime = 200)
GPIO.add_event_detect(tasterPin3, GPIO.FALLING, callback = call3, bouncetime = 200)

GPIO.add_event_detect(drehgeberPin1, GPIO.BOTH, callback = call4)
GPIO.add_event_detect(drehgeberPin2, GPIO.BOTH, callback = call4)

try:
    while True:
        time.sleep(1)

except KeyboardInterrupt:
    GPIO.cleanup()
    print ("Programm Beendet")

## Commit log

2018-03-19 src: Added java files for kiosk project graphical user interface The first prototype
2018-04-03 hw: CAD: Added designs for base components
    Added designs for
    - the LCD controller
    - the LCD
    - the powerlock
    Also added a first readme for the hardware section.
    [case.FCStd]
2018-05-03 Skript für Drehgeber und Taster Funktion
2018-05-03 Doku zu Taster und Drehgeber Software und Verschaltung
2018-05-09 hw: CAD: Added 2 CASE designs
    Added two case designs. One made from 2 IKEA Ribba Frames
    and the other prebuilt from RND.
    [case.FCStd]
2018-05-09 hw: schematic: Added power board schematic
    This board is, if used with gpio_poweroff and gpio_shutdown
    DT-Overlays, capable of cutting the power to the Raspberry
    and LCD Screen after shutdown.
    [kiosk_power_revB.brd, kiosk_power_revB.sch]
2018-05-09 hw: spice: Added spice simulation of Power board
    Added a basic LTSpice model for the Power board.
2018-05-13 hw: schematic: Updated schematic
    Increased relay coil series resistance to 220 ohms,
    which decreases power consumption.
    [kiosk_power_revB.brd, kiosk_power_revB.sch]
2018-05-14 hw: Updated readme
    The updated readme now contains the three sections
    CAD, schematic and simulation.
    [case.FCStd]
2018-05-21 src: bootloader: Added Raspberry Pi theme
    Added a plymouth theme which still needs
    the pngs rendered from the blender project.
2018-05-23 Drehgeber und Taster nur ueber Interrupts. Drehgeber noch nicht getestet.
2018-05-30 src: bootloader: Added delay to splashscreen
    Delayed pylmouth quit on startup and improved framerate.
2018-06-01 src: python: Logik: Removed syntax errors from interrupt reader
    [GPIO_Interrupt_DrehgeberUndTaster.py]
2018-06-01 src: python: Logik: Removed self deassert of eventcallbacks
    Removed the deassertion of the calling signal in the
    interrupt callbacks. They resulted in a segfault.
2018-06-02 src: python: Logik: Squashed the two encoder callbacks in one
    Also cleaned the python script.
2018-06-02 src: python: GUI_Test: Fixed the Infoscreen script
    Fixed parallel execution in the Infoscreen script
    with the use of signals and a smaller footprint.
2018-06-04 src: python: GUT_Test: Made html change functions more versatile
    Added argument to html change functions.
    Also added listener to quit app when hitting <ESC>,
    because the app is now displayed in fullscreen mode.
2018-06-21 hw: CAD: Updated CAD to freeCAD 0.17 and added new buttons
    [case.FCStd]
2018-06-21 hw: CAD: Added connector blocks to the corners of the case
    [case.FCStd]
2018-06-21 documentation: sw: Added prototype of the software/code documenation
2018-06-21 hw: schematic: Added button schematic
    [kiosk_buttons_revA.sch]
2018-06-21 hw: CAD: Added technical drawings to Design
    [case.FCStd]
2018-06-21 hw: CAD: Added paspartout document
2018-06-21 hw: CAD: Added new mount for RJ45 connector
    [case.FCStd]
